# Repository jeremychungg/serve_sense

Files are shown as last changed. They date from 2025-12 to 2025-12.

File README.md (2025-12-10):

ServeSense – Tennis Serve Insights
===================================

ServeSense is a wearable tennis serve analysis system built on the Seeed XIAO ESP32S3. The system includes:

1. **Data Logger** - Captures high-fidelity 6-axis IMU data (100 Hz) during serve motions via BLE
2. **ML Classifier** - Real-time on-device serve classification with TensorFlow Lite Micro
3. **Haptic Feedback** - Vibration motor patterns for each serve type
4. **Web GUI** - Browser-based visualization using Web Bluetooth API

The system classifies serves into 4 categories: good-serve, jerky-motion, lacks-pronation, and short-swing.

Hardware & Sensors
------------------

- **Microcontroller**: Seeed XIAO ESP32S3 Sense (or plain XIAO ESP32S3 + battery board)
- **IMU**: ICM-20600 6-axis sensor (or on-board BMI270)
- **Haptic Feedback**: Vibration motor on pin A0
- **Visual Feedback**: Built-in LED (LED_BUILTIN)
- **User Input**: Physical switch on pin D1
- **Connectivity**: BLE (ArduinoBLE library) for wireless data transmission

Current firmware assumes ICM-20600; adjust `imu_provider.cpp` for other IMU models.

Repository Layout
-----------------

- `firmware/serve_sense_logger/` – PlatformIO project for data collection; streams accel/gyro over BLE at 100 Hz with serve-segment markers. See logger directory for details.
- `firmware/serve_sense_classifier/` – TensorFlow Lite Micro inference app running real-time serve classification with haptic and LED feedback. Includes web-based GUI for visualization (see `README_CLASSIFIER.md`).
- `notebooks/` – Jupyter notebooks for data analysis, model training, and prototyping. Includes `ServeSense.ipynb` for end-to-end workflow.
- `models/` – Exported `.tflite` model files and metadata.
- `data/` – Raw and processed `.json` recordings (gitignored by default; see `data/.gitkeep`).

Getting Started
---------------

### Classifier GUI (Recommended for Testing)

The classifier includes a web-based GUI for real-time classification visualization:

1. Flash the classifier firmware:
   ```bash
   cd firmware/serve_sense_classifier
   pio run -t upload
   ```

2. Open `ServeSenseClassifier.html` in a Chrome/Edge browser (requires Web Bluetooth API)

3. Connect to your device and view:
   - Real-time serve classification (good-serve, jerky-motion, lacks-pronation, short-swing)
   - Confidence scores for all classes
   - Classification statistics
   - Haptic and LED feedback on the device

For detailed classifier documentation, see `firmware/serve_sense_classifier/README_CLASSIFIER.md`.

### Data Collection

1. Install Python dependencies:
   ```bash
   cd python
   pip install -r requirements.txt
   ```

2. Flash the logger firmware:
   ```bash
   cd firmware/serve_sense_logger
   pio run -t upload
   ```

3. Use the BLE collection script:
   ```bash
   cd python
   python collect_ble.py --out ../data/sessions/serve_001.parquet
   ```

4. Label and process data using notebooks in `notebooks/`

Choosing the First Model
------------------------

The current classifier uses a TensorFlow Lite Micro model with:
- **Input**: (160, 6) - 160 samples of 6-axis IMU data (3-axis accel + 3-axis gyro)
- **Output**: 4 classes - good-serve, jerky-motion, lacks-pronation, short-swing
- **Quantization**: int8 for efficient on-device inference
- **Threshold**: 35% confidence minimum for classification

The model was trained using data collected from the logger and processed in notebooks. To improve or retrain:
1. Collect more labeled serves using the logger
2. Process and augment data in `notebooks/ServeSense.ipynb`
3. Export the trained model as `.tflite` and convert to C array
4. Update `firmware/serve_sense_classifier/src/serve_model_data.cpp`

For specific documentation:
- **Classifier firmware**: See `firmware/serve_sense_classifier/README_CLASSIFIER.md`
- **Logger firmware**: See `firmware/serve_sense_logger/` directory
- **Data processing**: See notebooks in `notebooks/`

For issues and feature requests, visit the GitHub repository.

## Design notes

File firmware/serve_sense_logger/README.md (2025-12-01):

# Serve Sense Logger Firmware

Derived from the Magic Wand data collection sketch, this PlatformIO project streams ICM-20600 accel/gyro data over BLE and USB for tennis-serve capture.

## Build & Flash

```bash
cd firmware/serve_sense_logger
pio run -t upload
pio device monitor -b 115200
```

## Controls

- Press the XIAO BOOT button to toggle capture; the green LED mirrors capture state.
- `CTRL_UUID` commands (write single byte):
  - `0x00` – stop streaming / mark segment end
  - `0x01` – start new session and mark serve boundary
  - `0x02` – inject manual serve marker (e.g., voice cue)

## Packet Layout (36 bytes)

| Field | Type |
|---|---|
| millis_ms | uint32  |
| session | uint16  |
| sequence | uint16  |
| ax..gz | 6 × float32 |
| flags | uint8 (bit0=capture_on, bit1=marker_edge) |
| reserved | 3 × uint8 |

The Python collector consumes this payload via `collect_ble.py`.

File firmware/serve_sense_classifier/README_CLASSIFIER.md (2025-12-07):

# ServeSense Classifier

Real-time tennis serve classification using TensorFlow Lite on Xiao ESP32S3.

## Overview

This classifier runs a trained machine learning model on the Xiao ESP32S3 to identify different types of tennis serves and provide instant feedback via haptic vibration and LED patterns. The system classifies 4 distinct serve types based on technique quality.

### Serve Classifications

- ✅ **Good Serve** - Proper mechanics and execution
- ⚠️ **Jerky Motion** - Inconsistent or rough movement
- ⚠️ **Lacks Pronation** - Insufficient wrist pronation during contact
- ⚠️ **Short Swing** - Abbreviated or incomplete swing path

## Hardware Requirements

- **Xiao ESP32S3** with built-in IMU (ICM-20600)
- Physical switch connected to **D1 pin** (ON = LOW/closed to GND, OFF = HIGH/open)
- Vibration motor connected to **A0 pin** (for haptic feedback)
- USB cable for power and programming

## Software Requirements

- PlatformIO (for firmware upload)
- Chrome/Edge browser with Web Bluetooth support
- Trained TensorFlow Lite model (in `serve_model_data.cpp`)

## Setup Instructions

### 1. Flash Firmware to Xiao

```bash
cd firmware/serve_sense_classifier
pio run --target upload
```

### 2. Open Web Interface

**Option A: Web GUI (Recommended)**
1. Open `ServeSenseClassifier.html` in Chrome or Edge
2. Click "Connect to ServeSense"
3. Select your ServeSense device from the Bluetooth popup
4. Wait for connection confirmation

**Option B: Python GUI**
```bash
python classifier_gui.py
```

### 3. Record and Classify a Serve

1. **Start Recording**: Flip the switch to **ON** position (D1 → GND)
   - LED turns on solid
   - Vibration motor activates
   
2. **Perform Motion**: Execute your tennis serve

3. **Stop Recording**: Flip the switch to **OFF** position
   - LED turns off
   - Device processes classification (~1 second)

4. **Get Feedback**: 
   - **Haptic Pattern**: Distinctive vibration sequence
   - **LED Pattern**: Synchronized blink pattern
   - **Web Display**: Classification with confidence scores

### Feedback Patterns

**Good Serve** 🎾
- 3 quick pulses (100ms on, 100ms off)
- Feels celebratory!

**Jerky Motion** ⚡
- 2 long pulses (400ms on, 200ms off)
- Mimics the rough motion

**Lacks Pronation** ⚠️
- 1 long + 2 short pulses (500ms, then 2×100ms)
- Warning pattern

**Short Swing** 🔄
- 4 very short rapid pulses (80ms on, 80ms off)
- Feels quick and abbreviated

**Startup** ✅
- 1 second continuous pulse on boot
- Confirms hardware is working

## How It Works

### Firmware (Xiao ESP32S3)

1. **IMU Data Collection**: Reads 6-axis sensor data at ~40 Hz (ax, ay, az, gx, gy, gz)
2. **Buffer Management**: Stores 160 samples (4 seconds @ 40Hz) in memory
3. **Data Quantization**: Converts float32 IMU data to int8 for model input
4. **ML Inference**: Runs TensorFlow Lite Micro model on device
5. **Classification**: Outputs probabilities for all 4 serve types
6. **Multi-Modal Feedback**:
   - BLE transmission to web/Python GUI
   - Haptic vibration patterns via motor
   - Visual LED blink patterns
   - Serial output for debugging

### Web Interface

1. **BLE Connection**: Connects via Web Bluetooth API (UUID 0xFF00 service)
2. **Real-time Monitoring**: Tracks switch state and recording status
3. **Result Display**: Shows classification with color-coded prediction
4. **Confidence Bars**: Displays all 4 class probabilities visually
5. **Statistics**: Tracks total classifications and timestamps

## BLE Protocol

The classifier uses the same BLE protocol as ServeSense Logger for compatibility.

| UUID | Name | Type | Description |
|---|---|---|---|
| `0xFF00` | Service | - | Main BLE service |
| `0xFF01` | IMU Data | Notify | IMU packet stream (compatible with logger) |
| `0xFF02` | Control | Write | Start/stop commands (0x00=stop, 0x01=start) |
| `0xFF04` | Switch State | Notify | Recording state (0=idle, 1=recording) |
| `0xFF05` | Result | Notify | Classification results with all probabilities |

### Result Format

Classification results are sent as:
```
<label>:<conf1>,<conf2>,<conf3>,<conf4>
```

Where:
- `label` = predicted class name or "UNKNOWN"
- `conf1-4` = confidence percentages for [good-serve, jerky-motion, lacks-pronation, short-swing]

Example:
```
good-serve:87.3,5.2,4.1,3.4
```

## Confidence Thresholds

- **Minimum Confidence**: 35% (if below, result is "UNKNOWN")

This ensures the model only reports results when reasonably confident.

## Model Details

**Architecture:**
- Input: (160, 6) int8 tensor - 160 time steps × 6 IMU axes
- Output: (4,) int8 tensor - probabilities for 4 serve types
- Quantization: int8 post-training quantization for efficiency
- Size: ~80KB model + 80KB tensor arena

**Training:**
- Dataset: Tennis serve IMU recordings from multiple players
- Classes: good-serve, jerky-motion, lacks-pronation, short-swing
- Framework: TensorFlow → TensorFlow Lite → TFLite Micro

The model expects raw IMU data (ax, ay, az, gx, gy, gz) sampled at ~40Hz.

## Troubleshooting

### "Not Connected" in Web App
- Ensure Xiao is powered on and firmware is uploaded
- Use Chrome or Edge (Safari doesn't support Web Bluetooth)
- Check that device is advertising as "ServeSense"
- Try refreshing the page and reconnecting

### "UNKNOWN" Classifications
- Ensure you're performing a full serve motion (4 seconds)
- Record the entire swing from start to finish
- Check that motion has sufficient speed and rotation
- Verify the model file is correctly flashed

### No Haptic/LED Feedback
- Check vibration motor connection to A0
- Verify motor ground is connected
- Test motor by touching wires to 3.3V briefly
- LED should always blink on startup (1 second pulse)

### Switch Not Responding
- Verify switch is connected to D1 pin and GND
- Check that switch closes to GND when ON
- Test with multimeter: should read LOW (~0V) when ON
- LED should turn on solid when recording

### Serial Monitor Errors
Common messages:
- `ERROR: IMU initialization failed!` - Check I2C connections
- `ERROR: Inference failed!` - Model may be corrupted, re-upload firmware
- `Tensor allocation failed!` - Increase kTensorArenaSize in code

## Model Training

The TensorFlow Lite model is trained on labeled serve data and converted to C array format for embedded deployment.

**Training Pipeline:**
1. Collect serve data using ServeSense Logger
2. Label and preprocess IMU sequences
3. Train model in TensorFlow/Keras
4. Convert to TensorFlow Lite with int8 quantization
5. Generate C array using `xxd` or similar tool
6. Replace contents in `serve_model_data.cpp`

See the main ServeSense repository for training notebooks and scripts.

## Project Structure

```
serve_sense_classifier/
├── src/
│   ├── main.cpp                    # Main classification firmware
│   ├── imu_provider.cpp/h          # IMU interface (ICM-20600)
│   ├── constants.h                 # Configuration constants
│   ├── serve_model_data.cpp/h      # TFLite model (C array)
│   └── tflm_esp32_port.cpp         # TFLite Micro ESP32 port
├── lib/
│   └── Arduino_TensorFlowLite/     # TFLite Micro library
├── ServeSenseClassifier.html       # Web-based GUI
├── classifier_gui.py               # Python GUI (optional)
├── platformio.ini                  # Build configuration
└── README_CLASSIFIER.md            # This file
```

## Future Improvements

- [x] Add haptic feedback patterns
- [x] Add synchronized LED patterns
- [x] Display all class probabilities in web GUI
- [ ] Add real-time IMU visualization during recording
- [ ] Export classification history to CSV
- [ ] Add confidence calibration settings
- [ ] Multi-serve session analysis with statistics
- [ ] Battery percentage indicator

## Credits

Based on TensorFlow Lite Micro, adapted for real-time tennis serve classification with multi-modal feedback.

**Key Technologies:**
- TensorFlow Lite Micro for embedded ML
- ArduinoBLE for wireless communication
- ESP32 I2C for IMU interface
- ICM-20600 6-axis IMU sensor

---

**For training data collection, use the ServeSense Logger firmware. For model training and evaluation, see the main repository notebooks.**

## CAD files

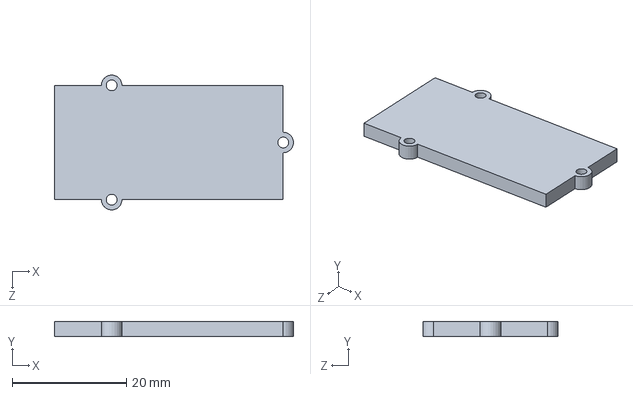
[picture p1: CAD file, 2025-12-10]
cad_models/9dof_imu_seeed.SLDPRT
41.8 x 2.60 x 23.6 mm

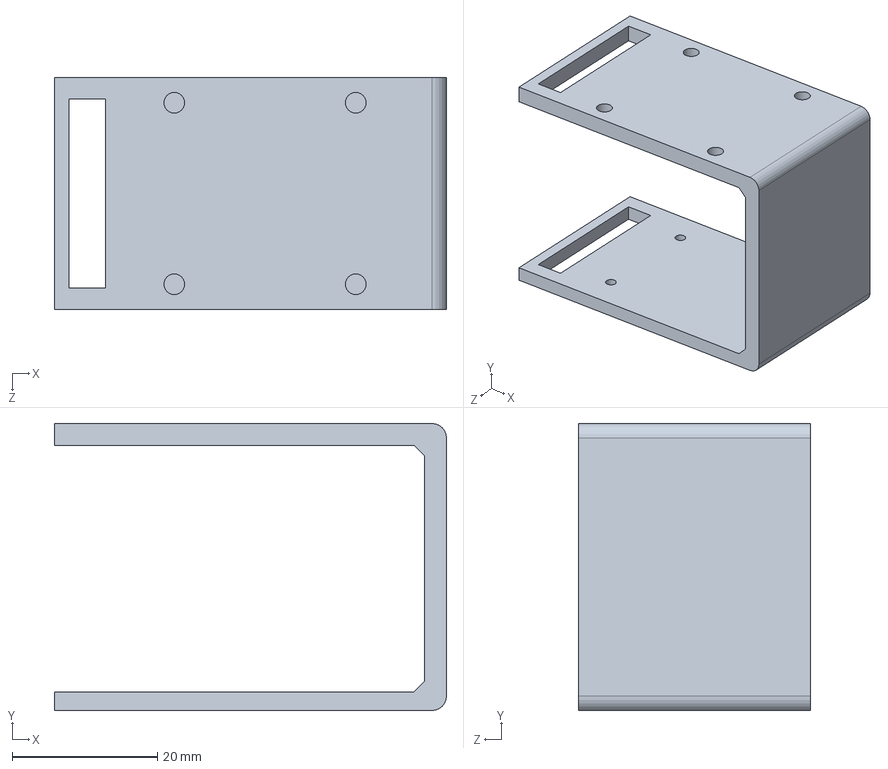
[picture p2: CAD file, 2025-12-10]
cad_models/imu_mount.SLDPRT
54.0 x 39.5 x 32.0 mm

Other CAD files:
cad_models/imu_mount_new.STL

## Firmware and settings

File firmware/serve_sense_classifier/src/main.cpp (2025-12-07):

/* ServeSense Classifier - Real-time Tennis Serve Classification
 * 
 * Collects 6-axis IMU data (ax, ay, az, gx, gy, gz) from ICM-20600
 * Uses switch on D1 pin to start/stop recording
 * Runs TensorFlow Lite inference to classify serve type
 * 
 * Model expects: (160, 6) int8 input
 * Classes: good-serve, jerky-motion, lacks-pronation, short-swing
 */

#include <Arduino.h>
#include <ArduinoBLE.h>

#include "tensorflow/lite/micro/micro_interpreter.h"
#include "tensorflow/lite/micro/micro_log.h"
#include "tensorflow/lite/micro/micro_mutable_op_resolver.h"
#include "tensorflow/lite/micro/system_setup.h"
#include "tensorflow/lite/schema/schema_generated.h"
#include "tensorflow/lite/version.h"

#include "imu_provider.h"
#include "serve_model_data.h"

// BLE UUIDs matching ServeSense logger protocol
#define SERVICE_UUID "0000ff00-0000-1000-8000-00805f9b34fb"
#define IMU_CHAR_UUID "0000ff01-0000-1000-8000-00805f9b34fb"     // IMU data packets
#define CTRL_CHAR_UUID "0000ff02-0000-1000-8000-00805f9b34fb"    // Control commands
#define SWITCH_CHAR_UUID "0000ff04-0000-1000-8000-00805f9b34fb"  // Switch state
#define RESULT_CHAR_UUID "0000ff05-0000-1000-8000-00805f9b34fb"  // Classification result

#define PIN_RECORD_SWITCH D1  // D1 on XIAO ESP32S3 (switch: ON=LOW, OFF=HIGH with pullup)
#define LED_BUILTIN LED_BUILTIN  // Built-in LED on XIAO ESP32S3
#define PIN_VIBRATION_MOTOR A0  // Vibration motor on A0

// ===== Model Configuration =====
constexpr int kSequenceLength = 160;  // 160 samples @ 40Hz = 4 seconds
constexpr int kNumFeatures = 6;       // ax, ay, az, gx, gy, gz
constexpr int kNumClasses = 4;        // good-serve, jerky-motion, lacks-pronation, short-swing

const char* labels[kNumClasses] = {
  "good-serve",
  "jerky-motion", 
  "lacks-pronation",
  "short-swing"
};

// ===== IMU Data Buffer =====
float imu_buffer[kSequenceLength][kNumFeatures];
int sample_count = 0;
bool is_recording = false;
bool last_switch_state = HIGH;

// ===== BLE Services =====
BLEService        service              (SERVICE_UUID);
BLECharacteristic imuCharacteristic    (IMU_CHAR_UUID, BLERead | BLENotify, 36);      // IMU packet stream
BLECharacteristic ctrlCharacteristic   (CTRL_CHAR_UUID, BLEWrite, 1);                 // Control (0x00=stop, 0x01=start)
BLECharacteristic switchCharacteristic (SWITCH_CHAR_UUID, BLERead | BLENotify, 1);    // Switch state
BLECharacteristic resultCharacteristic (RESULT_CHAR_UUID, BLERead | BLENotify, 64);   // Classification result

// ===== TensorFlow Lite Setup =====
namespace {
  const tflite::Model* model = nullptr;
  tflite::MicroInterpreter* interpreter = nullptr;
  TfLiteTensor* model_input = nullptr;
  TfLiteTensor* model_output = nullptr;

  constexpr int kTensorArenaSize = 80 * 1024;  // 80KB
  uint8_t tensor_arena[kTensorArenaSize];
}

void classifyServe();
void hapticGoodServe();
void hapticJerkyMotion();
void hapticLacksPronation();
void hapticShortSwing();
void hapticStartup();

void setup() {
  delay(1000);
  
  tflite::InitializeTarget();
  
  Serial.println("\n=== ServeSense Classifier ===");
  
  // Setup LED pin
  pinMode(LED_BUILTIN, OUTPUT);
  digitalWrite(LED_BUILTIN, LOW);  // LED off initially
  
  // Setup vibration motor
  pinMode(PIN_VIBRATION_MOTOR, OUTPUT);
  digitalWrite(PIN_VIBRATION_MOTOR, LOW);
  hapticStartup();  // Startup pulse
  
  // Setup switch pin (start in ON position)
  pinMode(PIN_RECORD_SWITCH, INPUT_PULLUP);
  last_switch_state = LOW;  // Initialize as if switch is ON
  
  // Initialize IMU
  if (!SetupIMU()) {
    Serial.println("ERROR: IMU initialization failed!");
    while (1) delay(100);
  }
  Serial.println("✓ IMU initialized");
  
  // Setup BLE
  if (!BLE.begin()) {
    Serial.println("ERROR: BLE initialization failed!");
    while (1) delay(100);
  }
  
  BLE.setLocalName("ServeSense");
  BLE.setAdvertisedService(service);
  service.addCharacteristic(imuCharacteristic);
  service.addCharacteristic(ctrlCharacteristic);
  service.addCharacteristic(switchCharacteristic);
  service.addCharacteristic(resultCharacteristic);
  BLE.addService(service);
  BLE.advertise();
  Serial.println("✓ BLE advertising as 'ServeSense'");
  
  // Load TensorFlow Lite model
  model = tflite::GetModel(g_serve_model_data);
  if (model->version() != TFLITE_SCHEMA_VERSION) {
    Serial.print("ERROR: Model version mismatch! Expected ");
    Serial.print(TFLITE_SCHEMA_VERSION);
    Serial.print(", got ");
    Serial.println(model->version());
    while (1) delay(100);
  }
  Serial.println("✓ Model loaded");
  
  // Setup TensorFlow Lite interpreter
  static tflite::MicroMutableOpResolver<10> resolver;
  resolver.AddConv2D();
  resolver.AddMaxPool2D();
  resolver.AddReshape();
  resolver.AddFullyConnected();
  resolver.AddSoftmax();
  resolver.AddQuantize();
  resolver.AddDequantize();
  resolver.AddMean();
  resolver.AddPad();
  resolver.AddExpandDims();
  
  static tflite::MicroInterpreter static_interpreter(
    model, resolver, tensor_arena, kTensorArenaSize);
  interpreter = &static_interpreter;
  
  if (interpreter->AllocateTensors() != kTfLiteOk) {
    Serial.println("ERROR: Tensor allocation failed!");
    while (1) delay(100);
  }
  
  model_input = interpreter->input(0);
  model_output = interpreter->output(0);
  
  Serial.print("✓ Model ready - Input shape: (");
  Serial.print(model_input->dims->data[1]);
  Serial.print(", ");
  Serial.print(model_input->dims->data[2]);
  Serial.print("), Output classes: ");
  Serial.println(kNumClasses);
  
  Serial.println("\n[Ready - flip switch to D1 to record serve]");
}

void loop() {
  BLE.poll();
  
  // Check switch state
  bool switch_on = (digitalRead(PIN_RECORD_SWITCH) == LOW);
  
  // Detect switch state changes
  if (switch_on && !last_switch_state) {
    // Switch turned ON: start recording
    is_recording = true;
    sample_count = 0;
    digitalWrite(LED_BUILTIN, LOW);  // Turn LED on
    Serial.println("\n[RECORDING STARTED]");
    
    // Notify BLE
    uint8_t state = 1;
    switchCharacteristic.writeValue(state);
    
  } else if (!switch_on && last_switch_state && is_recording) {
    // Switch turned OFF: stop recording and classify
    is_recording = false;
    digitalWrite(LED_BUILTIN, HIGH);  // Turn LED off
    Serial.print("[RECORDING STOPPED] ");
    Serial.print(sample_count);
    Serial.println(" samples collected");
    
    // Notify BLE
    uint8_t state = 0;
    switchCharacteristic.writeValue(state);
    
    // Run classification
    if (sample_count > 0) {
      classifyServe();
    }
  }
  
  last_switch_state = switch_on;
  
  // Read IMU data while recording
  if (is_recording && sample_count < kSequenceLength) {
    float accel[3], gyro[3];
    if (ReadIMU(accel, gyro)) {
      // Store in buffer: ax, ay, az, gx, gy, gz
      imu_buffer[sample_count][0] = accel[0];
      imu_buffer[sample_count][1] = accel[1];
      imu_buffer[sample_count][2] = accel[2];
      imu_buffer[sample_count][3] = gyro[0];
      imu_buffer[sample_count][4] = gyro[1];
      imu_buffer[sample_count][5] = gyro[2];
      
      sample_count++;
      
      // Print progress every 20 samples
      if (sample_count % 20 == 0) {
        Serial.print(".");
      }
    }
    delay(25);  // ~40Hz sampling rate
  }
  
  delay(5);
}

void classifyServe() {
  Serial.println("\n>>> CLASSIFYING SERVE <<<");
  
  // Pad or truncate to exactly 160 samples
  int actual_samples = min(sample_count, kSequenceLength);
  
  // Get quantization parameters
  const float input_scale = model_input->params.scale;
  const int input_zp = model_input->params.zero_point;
  
  Serial.print("Quantization - scale: ");
  Serial.print(input_scale, 6);
  Serial.print(", zero_point: ");
  Serial.println(input_zp);
  
  // Fill model input with quantized IMU data
  for (int i = 0; i < kSequenceLength; i++) {
    for (int j = 0; j < kNumFeatures; j++) {
      float value;
      if (i < actual_samples) {
        value = imu_buffer[i][j];
      } else {
        value = 0.0f;  // Pad with zeros if needed
      }
      
      // Quantize: q = round(value / scale) + zero_point
      int32_t quantized = static_cast<int32_t>(roundf(value / input_scale)) + input_zp;
      
      // Clamp to int8 range
      if (quantized < -128) quantized = -128;
      if (quantized > 127) quantized = 127;
      
      model_input->data.int8[i * kNumFeatures + j] = static_cast<int8_t>(quantized);
    }
  }
  
  // Run inference
  if (interpreter->Invoke() != kTfLiteOk) {
    Serial.println("ERROR: Inference failed!");
    return;
  }
  
  // Dequantize outputs
  const float output_scale = model_output->params.scale;
  const int output_zp = model_output->params.zero_point;
  
  float probabilities[kNumClasses];
  int best_idx = 0;
  float max_prob = -1.0f;
  
  Serial.println("\nResults:");
  for (int i = 0; i < kNumClasses; i++) {
    // Dequantize: value = (q - zero_point) * scale
    float prob = (model_output->data.int8[i] - output_zp) * output_scale;
    probabilities[i] = prob;
    
    Serial.print("  ");
    Serial.print(labels[i]);
    Serial.print(": ");
    Serial.print(prob * 100, 1);
    Serial.println("%");
    
    if (prob > max_prob) {
      max_prob = prob;
      best_idx = i;
    }
  }
  
  // Determine if confident enough
  const float kMinConfidence = 0.35f;
  bool is_confident = max_prob >= kMinConfidence;
  
  char result_msg[64];
  if (is_confident) {
    Serial.print("\n✓ Prediction: ");
    Serial.print(labels[best_idx]);
    Serial.print(" (");
    Serial.print(max_prob * 100, 1);
    Serial.println("%)");
    
    // Send all probabilities: "best_class:conf1,conf2,conf3,conf4"
    snprintf(result_msg, sizeof(result_msg), "%s:%.1f,%.1f,%.1f,%.1f", 
             labels[best_idx], 
             probabilities[0] * 100, 
             probabilities[1] * 100, 
             probabilities[2] * 100, 
             probabilities[3] * 100);
  } else {
    Serial.print("\n? Prediction: UNKNOWN (max confidence: ");
    Serial.print(max_prob * 100, 1);
    Serial.println("%)");
    
    // Send all probabilities even for UNKNOWN
    snprintf(result_msg, sizeof(result_msg), "UNKNOWN:%.1f,%.1f,%.1f,%.1f", 
             probabilities[0] * 100, 
             probabilities[1] * 100, 
             probabilities[2] * 100, 
             probabilities[3] * 100);
  }
  
  // Send result over BLE
  resultCharacteristic.writeValue((uint8_t*)result_msg, strlen(result_msg));
  
  // Haptic feedback based on classification
  if (is_confident) {
    if (best_idx == 0) {  // good-serve
      hapticGoodServe();
    } else if (best_idx == 1) {  // jerky-motion
      hapticJerkyMotion();
    } else if (best_idx == 2) {  // lacks-pronation
      hapticLacksPronation();
    } else if (best_idx == 3) {  // short-swing
      hapticShortSwing();
    }
  }
  
  // Ensure LED is off after feedback
  digitalWrite(LED_BUILTIN, HIGH);
  
  Serial.println("\n[Ready - flip switch to record another serve]");
}

// ===== Haptic Feedback Functions =====
void hapticStartup() {
  // Startup: 1 second continuous pulse
  digitalWrite(PIN_VIBRATION_MOTOR, HIGH);
  digitalWrite(LED_BUILTIN, HIGH);
  delay(1000);
  digitalWrite(PIN_VIBRATION_MOTOR, LOW);
  digitalWrite(LED_BUILTIN, LOW);
}

void hapticGoodServe() {
  // Good serve: 3 quick happy pulses (short-short-short)
  for (int i = 0; i < 3; i++) {
    digitalWrite(PIN_VIBRATION_MOTOR, HIGH);
    digitalWrite(LED_BUILTIN, HIGH);
    delay(100);
    digitalWrite(PIN_VIBRATION_MOTOR, LOW);
    digitalWrite(LED_BUILTIN, LOW);
    delay(100);
  }
}

void hapticJerkyMotion() {
  // Jerky motion: 2 long pulses (rough/jerky feeling)
  for (int i = 0; i < 2; i++) {
    digitalWrite(PIN_VIBRATION_MOTOR, HIGH);
    digitalWrite(LED_BUILTIN, HIGH);
    delay(400);
    digitalWrite(PIN_VIBRATION_MOTOR, LOW);
    digitalWrite(LED_BUILTIN, LOW);
    delay(200);
  }
}

void hapticLacksPronation() {
  // Lacks pronation: 1 long pulse + 2 short (warning pattern)
  digitalWrite(PIN_VIBRATION_MOTOR, HIGH);
  digitalWrite(LED_BUILTIN, HIGH);
  delay(500);
  digitalWrite(PIN_VIBRATION_MOTOR, LOW);
  digitalWrite(LED_BUILTIN, LOW);
  delay(150);
  for (int i = 0; i < 2; i++) {
    digitalWrite(PIN_VIBRATION_MOTOR, HIGH);
    digitalWrite(LED_BUILTIN, HIGH);
    delay(100);
    digitalWrite(PIN_VIBRATION_MOTOR, LOW);
    digitalWrite(LED_BUILTIN, LOW);
    delay(100);
  }
}

void hapticShortSwing() {
  // Short swing: 4 very short rapid pulses (short-short-short-short)
  for (int i = 0; i < 4; i++) {
    digitalWrite(PIN_VIBRATION_MOTOR, HIGH);
    digitalWrite(LED_BUILTIN, HIGH);
    delay(80);
    digitalWrite(PIN_VIBRATION_MOTOR, LOW);
    digitalWrite(LED_BUILTIN, LOW);
    delay(80);
  }
}

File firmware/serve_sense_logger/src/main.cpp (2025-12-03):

#include <Arduino.h>
#include <Wire.h>
#include <NimBLEDevice.h>

// ---------- I2C pins & ICM20600 config ----------
#define I2C_SDA 5
#define I2C_SCL 6
#define ICM20600_ADDR 0x69

#define PIN_CAPTURE_BTN 0  // BOOT button (active low)
#define PIN_RECORD_SWITCH D1  // D1 on XIAO ESP32S3 (switch: ON=LOW starts recording, with pullup)
#define PIN_STATUS_LED 21  // Built-in LED on XIAO ESP32S3

#define REG_PWR_MGMT_1   0x6B
#define REG_ACCEL_CONFIG 0x1C
#define REG_GYRO_CONFIG  0x1B
#define REG_ACCEL_XOUT_H 0x3B
#define REG_WHO_AM_I     0x75

// conversions for ±2g accel, ±250 dps gyro
static const float ACC_LSB_PER_G   = 16384.0f;
static const float GYR_LSB_PER_DPS = 131.0f;

// ---------- BLE UUIDs ----------
static const NimBLEUUID SVC_UUID ((uint16_t)0xFF00);
static const NimBLEUUID IMU_UUID ((uint16_t)0xFF01);  // notify
static const NimBLEUUID CTRL_UUID((uint16_t)0xFF02);  // write

// ---------- Globals ----------
NimBLECharacteristic* imuChar = nullptr;
volatile bool streamOn = true;
const uint32_t PERIOD_MS = 25;  // ~40 Hz

// ServeSense specific globals
volatile bool captureEnabled = false;
volatile bool serveMarker = false;
uint32_t sessionId = 0;
uint32_t sampleSerial = 0;

// ServeSense packet structure
struct ServePacket {
  uint32_t millis_ms;
  uint32_t session;
  uint32_t sequence;
  float ax, ay, az;
  float gx, gy, gz;
  uint8_t flags;
} __attribute__((packed));

// ---------- I2C helpers ----------
static bool i2cWrite(uint8_t reg, uint8_t val) {
  Wire.beginTransmission((uint8_t)ICM20600_ADDR);
  Wire.write(reg);
  Wire.write(val);
  return Wire.endTransmission() == 0;
}

static bool i2cReadBytes(uint8_t reg, uint8_t* buf, size_t len) {
  Wire.beginTransmission((uint8_t)ICM20600_ADDR);
  Wire.write(reg);
  if (Wire.endTransmission(false) != 0) return false;

  if (Wire.requestFrom((uint8_t)ICM20600_ADDR, (uint8_t)len) != (int)len) return false;
  for (size_t i = 0; i < len; ++i) {
    buf[i] = Wire.read();
  }
  return true;
}

static bool icmInit(uint8_t& who) {
  who = 0;
  if (!i2cWrite(REG_PWR_MGMT_1, 0x01)) return false;  // wake, PLL
  delay(50);
  if (!i2cWrite(REG_ACCEL_CONFIG, 0x00)) return false; // ±2g
  if (!i2cWrite(REG_GYRO_CONFIG,  0x00)) return false; // ±250 dps
  delay(10);
  return i2cReadBytes(REG_WHO_AM_I, &who, 1);
}

static bool icmRead(float& ax,float& ay,float& az,
                    float& gx,float& gy,float& gz) {
  uint8_t raw[14];
  if (!i2cReadBytes(REG_ACCEL_XOUT_H, raw, sizeof(raw))) return false;

  auto s16 = [&](int i)->int16_t {
    return (int16_t)((raw[i] << 8) | raw[i+1]);
  };

  ax = s16(0)  / ACC_LSB_PER_G;
  ay = s16(2)  / ACC_LSB_PER_G;
  az = s16(4)  / ACC_LSB_PER_G;

  gx = s16(8)  / GYR_LSB_PER_DPS;
  gy = s16(10) / GYR_LSB_PER_DPS;
  gz = s16(12) / GYR_LSB_PER_DPS;

  return true;
}

// ---------- BLE callbacks ----------
class CbServer : public NimBLEServerCallbacks {
  void onConnect(NimBLEServer* server) {
    Serial.print("[BLE] Central connected\r\n");
  }
  
  void onDisconnect(NimBLEServer*) {
    Serial.print("[BLE] Central disconnected\r\n");
    Serial.print("[BLE] Restarting advertising\r\n");
    NimBLEDevice::startAdvertising();
  }
};

class CbCtrl : public NimBLECharacteristicCallbacks {
  void onWrite(NimBLECharacteristic* c) {
    auto v = c->getValue();
    if (v.size() > 0) {
      streamOn = (v[0] != 0);
      Serial.print("[CTRL] streamOn = ");
      Serial.print(streamOn ? 1 : 0);
      Serial.print("\r\n");
    }
  }
};

void IRAM_ATTR onButtonFalling() {
  static uint32_t last = 0;
  uint32_t now = millis();
  if (now - last < 200) return; // debounce
  last = now;
  captureEnabled = !captureEnabled;
  if (captureEnabled) {
    sessionId++;
    sampleSerial = 0;
  }
  serveMarker = true;
}

// ============================================================
// Setup
// ============================================================

void setup() {
  // ESP32S3 XIAO USB CDC setup
  Serial.begin(115200);
  pinMode(PIN_CAPTURE_BTN, INPUT_PULLUP);
  pinMode(PIN_RECORD_SWITCH, INPUT_PULLUP); // Switch: LOW = ON (closed to GND/right), HIGH = OFF (open or VCC/left)
  pinMode(PIN_STATUS_LED, OUTPUT);
  digitalWrite(PIN_STATUS_LED, LOW); // Start with LED off



  attachInterrupt(digitalPinToInterrupt(PIN_CAPTURE_BTN), onButtonFalling, FALLING);

  // Wait for USB CDC to be ready on ESP32S3 in Windows environment
  while (!Serial && millis() < 5000) {
    delay(10);
  }
  delay(1000);
  Serial.flush();
  
  Serial.println("\n[BOOT] ServeSense Logger");

  // I2C + IMU
  Wire.begin(I2C_SDA, I2C_SCL, 400000);
  Serial.print("[I2C] Initializing ICM20600...\r\n");
  
  uint8_t who = 0;
  if (icmInit(who)) {
    Serial.print("[I2C] ICM20600 OK, WHO_AM_I=0x");
    Serial.print(who, HEX);
    Serial.print(" (addr 0x");
    Serial.print(ICM20600_ADDR, HEX);
    Serial.print(")\r\n");
  } else {
    Serial.print("[I2C] ICM init FAILED\r\n");
  }

  // BLE setup
  Serial.print("[BLE] Initializing NimBLE...\r\n");
  NimBLEDevice::init("ServeSense");
  NimBLEDevice::setMTU(128);
  NimBLEDevice::setPower(ESP_PWR_LVL_P9);
  NimBLEDevice::setSecurityAuth(false,false,false);

  auto server = NimBLEDevice::createServer();
  server->setCallbacks(new CbServer());

  auto svc = server->createService(SVC_UUID);
  imuChar = svc->createCharacteristic(
      IMU_UUID, NIMBLE_PROPERTY::NOTIFY
  );
  auto ctrl = svc->createCharacteristic(
      CTRL_UUID, NIMBLE_PROPERTY::WRITE
  );
  ctrl->setCallbacks(new CbCtrl());
  svc->start();

  auto adv = NimBLEDevice::getAdvertising();
  adv->addServiceUUID(SVC_UUID);
  
  adv->setMinInterval(32);
  adv->setMaxInterval(244);
  
  // Enhanced discoverability
  adv->setName("ServeSense");
  adv->setAppearance(0x0040); 
  
  adv->start();

  Serial.print("[BLE] Advertising as S with svc 0xFF00\r\n");
  Serial.print("========================================\r\n");
  Serial.print("[SETUP] Ready for connections!\r\n");
  Serial.print("========================================\r\n");
}
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

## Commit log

2025-12-02 fixed button to start recording data we switched. gui also updated for data collection
    [main.cpp]
2025-12-07 Add ServeSense Classifier with real-time classification, BLE protocol, haptic/LED feedback, and web GUI
2025-12-07 Update main README to reflect current implementation and cleaned repository structure
2025-12-10 3d cad files in folder
    [9dof_imu_seeed.SLDPRT, imu_mount.SLDPRT, imu_mount_new.STL]
